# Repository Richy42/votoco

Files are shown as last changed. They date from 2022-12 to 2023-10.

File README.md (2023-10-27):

# Voron Tool Controller
A 3D printer controller board

Inspired by the possibility of Klipper 3D printer firmware (https://www.klipper3d.org/) that allows to have several I/O controller boards, Voron Tool Controller is a small board intended to be mounted on the moving print head assembly of a Voron 3D printer.

This reduces the cabling effort significantly as only power supply and CAN is needed.

PrintHeadController has the following features:
* Based on STM32 , so it is supported by the Klipper firmware out of the box
* TMC2209 on board for the extruder
* Supports the UART configuration of TMC driver
* 12 V and 24 V capable
* 2 Digital inputs
* 3 MOSFET outputs (e.g. hotend heater, fans)
* 1 Thermistor inputs
* BLTouch support
* Debug pins accessible
* Accelerometer ADXL245
* Don't Touch It connector (https://github.com/Richy42/DontTouchIt)









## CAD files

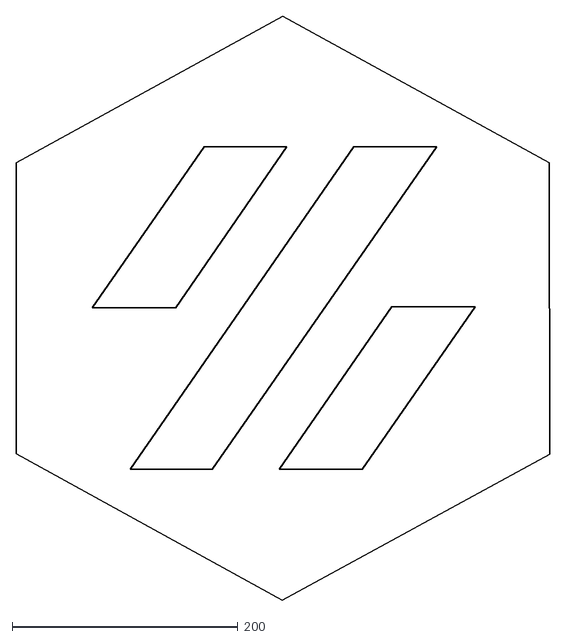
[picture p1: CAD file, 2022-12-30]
kicad/Voron_Design_Plain_Logo.dxf
472.7 x 517.8

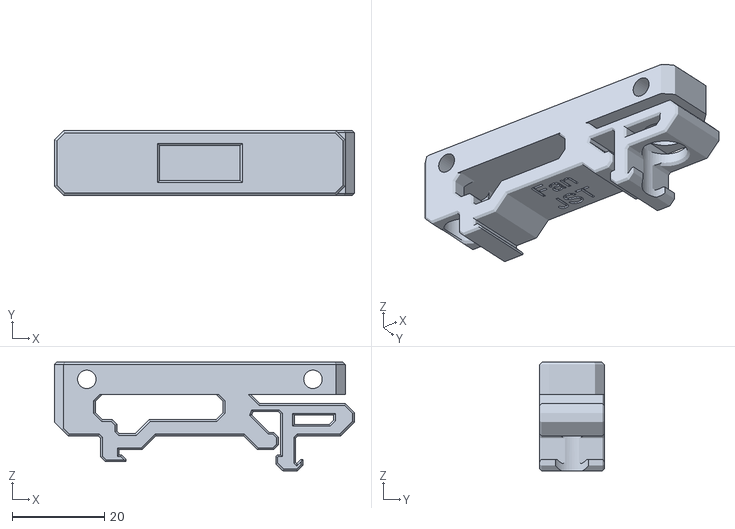
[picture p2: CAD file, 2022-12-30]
kicad/votoco/fan_jst_bracket.stl
65.0 x 14.0 x 23.6

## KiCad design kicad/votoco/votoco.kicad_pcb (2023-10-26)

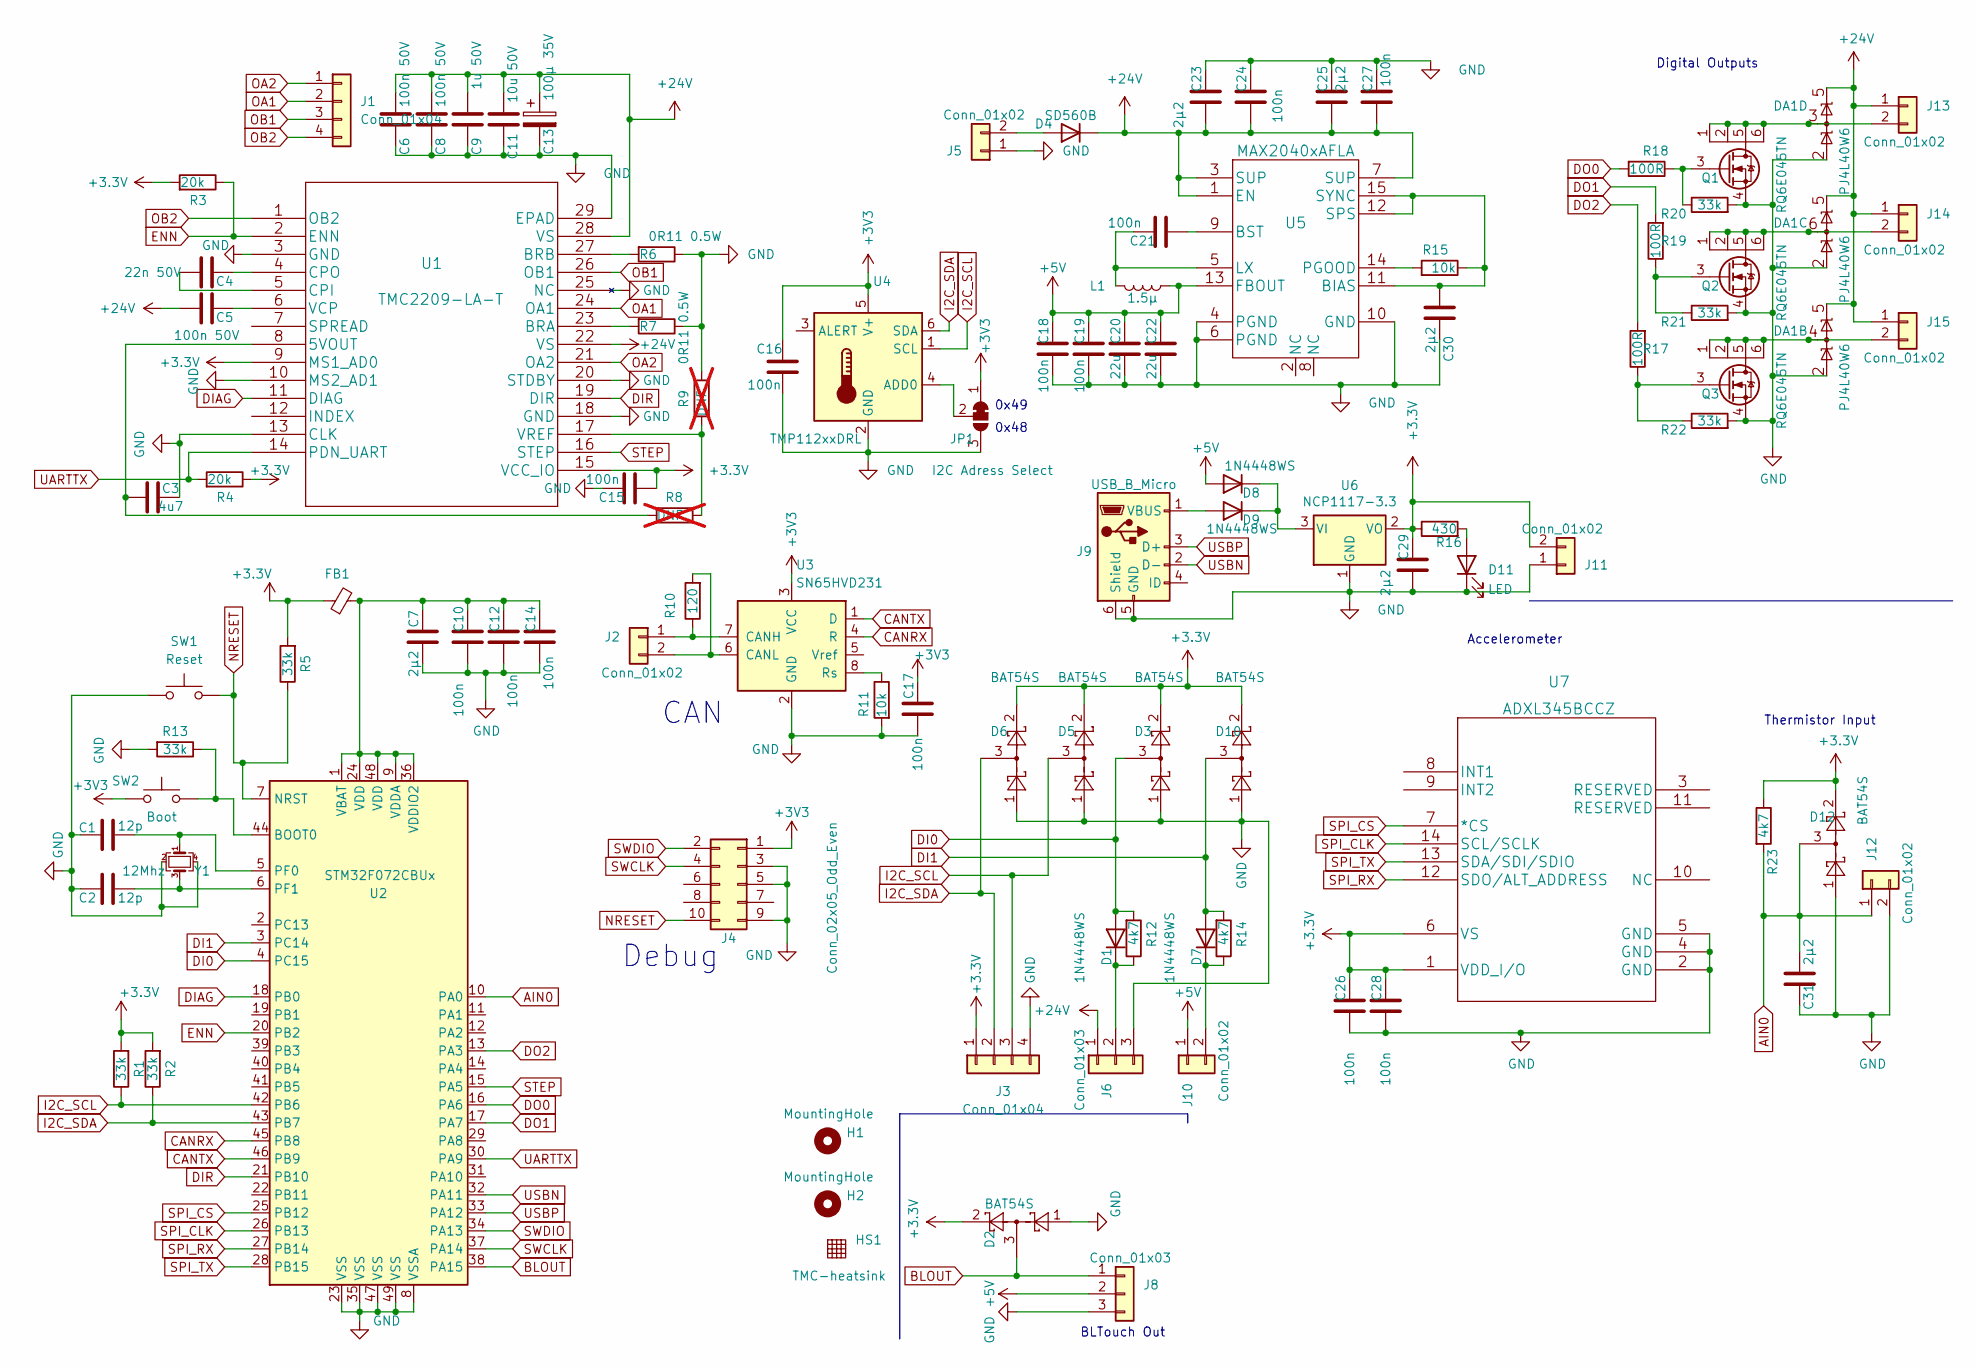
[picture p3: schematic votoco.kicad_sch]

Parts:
C1, C2: 12p; C_0603_1608Metric
C3: 4u7; C_0603_1608Metric
C4: 22n 50V; C_0603_1608Metric
C5, C6, C8: 100n 50V; C_0603_1608Metric
C7, C23, C25, C29, C30, C31: 2µ2; C_0603_1608Metric
C9: 1u 50V; C_0603_1608Metric
C10, C12, C14, C15, C16, C17, C18, C19, C21, C24, C26, C27, C28: 100n; C_0603_1608Metric
C11: 10u 50V; C_0603_1608Metric
C13: 100µ 35V; CP_Elec_6.3x7.7
C20, C22: 22u; C_0603_1608Metric
D1, D7, D8, D9: 1N4448WS; D_SOD-323
D2, D3, D5, D6, D10, D12: BAT54S; SOT-23
D4: SD560B; D_SMB
D11: LED; LED_0603_1608Metric
DA1: PJ4L40W6; SOT-23-6
FB1: FerriteBead_Small; L_0603_1608Metric
H1, H2: MountingHole; MountingHole_3.2mm_M3
HS1: TMC-heatsink
J1, J3: Conn_01x04; JST_PH_B4B-PH-SM4-TB_1x04-1MP_P2.00mm_Vertical
J2, J10, J11, J12, J13, J14, J15: Conn_01x02; JST_PH_B2B-PH-SM4-TB_1x02-1MP_P2.00mm_Vertical
J4: Conn_02x05_Odd_Even; PinHeader_2x05_P1.27mm_Vertical_SMD
J5: Conn_01x02; JST_VH_B2P-VH-B_1x02_P3.96mm_Vertical
J6, J8: Conn_01x03; JST_PH_B3B-PH-SM4-TB_1x03-1MP_P2.00mm_Vertical
J9: USB_B_Micro; USB_Micro-B_Wuerth_614105150721_Vertical_CircularHoles
JP1: I2C Adress Select; SolderJumper-3_P1.3mm_Bridged12_RoundedPad1.0x1.5mm
L1: 1.5µ; L_0805_2012Metric
Q1, Q2, Q3: RQ6E045TN; SOT-457T
R1, R2, R5, R13, R20, R21, R22: 33k; R_0603_1608Metric
R3, R4: 20k; R_0603_1608Metric
R6, R7: 0R11 0.5W; R_0805_2012Metric
R8, R9: DNF; R_0603_1608Metric; not fitted
R10: 120; R_0603_1608Metric
R11, R15: 10k; R_0603_1608Metric
R12, R14, R23: 4k7; R_0603_1608Metric
R16: 430; R_0603_1608Metric
R17, R18, R19: 100R; R_0603_1608Metric
SW1: Reset; SW_Push_1P1T-Pana_EVPAA
SW2: Boot; SW_Push_1P1T-Pana_EVPAA
U1: TMC2209-LA-T
U2: STM32F072CBUx; UFQFPN-48_EP_7x7_Pitch0.5mm
U3: SN65HVD231; SOIC-8_3.9x4.9mm_P1.27mm
U4: TMP112xxDRL; SOT-563
U5: MAX2040xAFLA; MAX2040xAFL
U6: NCP1117-3.3; SOT-223-3_TabPin2
U7: ADXL345BCCZ
Y1: 12Mhz; Crystal_SMD_2520-4Pin_2.5x2.0mm

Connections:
+5V: C18.1, C19.1, C20.2, C22.2, D8.2 (A), J8.2, J10.1, L1.1, U5.13 (FBOUT)
+24V: C5.2, C6.1, C8.1, C9.1, C11.1, C13.1, C23.2, C24.2, C25.2, C27.2, D4.1 (K), DA1.5, J6.1, J13.1, J14.1, J15.1, U1.22 (VS), U1.28 (VS), U5.1 (EN), U5.3 (SUP), U5.7 (SUP)
AIN0: C31.1, D12.3, J12.1, R23.2, U2.10 (PA0)
BLOUT: D2.3, J8.1, U2.38 (PA15)
CANRX: U2.45 (PB8), U3.4 (R)
CANTX: U2.46 (PB9), U3.1 (D)
DI0: D1.2 (A), D3.3, R12.2, U2.4 (PC15)
DI1: D7.2 (A), D10.3, R14.2, U2.3 (PC14)
DIAG: U1.11 (DIAG), U2.18 (PB0)
DIR: U1.19 (DIR), U2.21 (PB10)
DO0: R18.2, U2.16 (PA6)
DO1: R19.2, U2.17 (PA7)
DO2: R17.2, U2.13 (PA3)
ENN: R3.1, U1.2 (ENN), U2.20 (PB2)
GND: C1.1, C2.1, C3.1, C6.2, C7.2, C8.2, C9.2, C10.2, C11.2, C12.2, C13.2, C14.2, C15.1, C16.2, C17.2, C18.2, C19.2, C20.1, C22.1, C23.1, C24.1, C25.1, C26.2, C27.1, C28.2, C29.2, C30.2, C31.2, D2.1, D3.1, D5.1, D6.1, D10.1, D11.1 (K), D12.1, DA1.2, J3.4, J4.3, J4.5, J4.9, J5.1, J6.3, J8.3, J9.5 (GND), J9.6 (Shield), J11.1, J12.2, JP1.3 (B), Q1.4 (S), Q2.4 (S), Q3.4 (S), R6.1, R7.1, R9.2, R11.2, R13.2, R20.2, R21.2, R22.2, SW1.1, U1.3 (GND), U1.10 (MS2_AD1), U1.13 (CLK), U1.18 (GND), U1.20 (STDBY), U1.25 (NC), U1.29 (EPAD), U2.8 (VSSA), U2.23 (VSS), U2.35 (VSS), U2.47 (VSS), U2.49 (VSS), U3.2 (GND), U4.2 (GND), U5.4 (PGND), U5.6 (PGND), U5.10 (GND), U6.1 (GND), U7.2 (GND), U7.4 (GND), U7.5 (GND), Y1.2, Y1.4
I2C_SCL: D5.3, J3.3, R1.1, U2.42 (PB6), U4.1 (SCL)
I2C_SDA: D6.3, J3.2, R2.1, U2.43 (PB7), U4.6 (SDA)
NRESET: J4.10, R5.1, SW1.2, U2.7 (NRST)
unnamed: D1.1 (K), J6.2, R12.1
unnamed: D4.2 (A), J5.2
unnamed: D7.1 (K), J10.2, R14.1
unnamed: D8.1 (K), D9.1 (K), U6.3 (VI)
unnamed: D9.2 (A), J9.1 (VBUS)
unnamed: D11.2 (A), R16.2
unnamed: J2.1, R10.1, U3.7 (CANH)
unnamed: J2.2, R10.2, U3.6 (CANL)
unnamed: DA1.3, J13.2, Q1.1 (D), Q1.2 (D), Q1.5 (D), Q1.6 (D)
unnamed: DA1.6, J14.2, Q2.1 (D), Q2.2 (D), Q2.5 (D), Q2.6 (D)
unnamed: DA1.4, J15.2, Q3.1 (D), Q3.2 (D), Q3.5 (D), Q3.6 (D)
unnamed: JP1.2 (C), U4.4 (ADD0)
unnamed: Q1.3 (G), R18.1, R20.1
unnamed: Q2.3 (G), R19.1, R21.1
unnamed: Q3.3 (G), R17.1, R22.1
unnamed: C3.2, R8.1, U1.8 (5VOUT)
unnamed: R7.2, U1.23 (BRA)
unnamed: R6.2, U1.27 (BRB)
unnamed: C4.2, U1.5 (CPI)
unnamed: C4.1, U1.4 (CPO)
unnamed: C5.1, U1.6 (VCP)
unnamed: R8.2, R9.1, U1.17 (VREF)
unnamed: R13.1, SW2.2, U2.44 (BOOT0)
unnamed: C1.2, U2.5 (PF0), Y1.1
unnamed: C2.2, U2.6 (PF1), Y1.3
unnamed: C7.1, C10.1, C12.1, C14.1, FB1.2, U2.1 (VBAT), U2.9 (VDDA), U2.24 (VDD), U2.36 (VDDIO2), U2.48 (VDD)
unnamed: R11.1, U3.8 (Rs)
unnamed: C30.1, R15.1, U5.11 (BIAS), U5.12 (SPS), U5.15 (SYNC)
unnamed: C21.2, U5.9 (BST)
unnamed: C21.1, L1.2, U5.5 (LX)
unnamed: R15.2, U5.14 (PGOOD)
OA1: J1.2, U1.24 (OA1)
OA2: J1.1, U1.21 (OA2)
OB1: J1.3, U1.26 (OB1)
OB2: J1.4, U1.1 (OB2)
SPI_CLK: U2.26 (PB13), U7.14 (SCL/SCLK)
SPI_CS: U2.25 (PB12), U7.7 (*CS)
SPI_RX: U2.27 (PB14), U7.12 (SDO/ALT_ADDRESS)
SPI_TX: U2.28 (PB15), U7.13 (SDA/SDI/SDIO)
STEP: U1.16 (STEP), U2.15 (PA5)
SWCLK: J4.4, U2.37 (PA14)
SWDIO: J4.2, U2.34 (PA13)
UARTTX: R4.2, U1.14 (PDN_UART), U2.30 (PA9)
USBN: J9.2 (D-), U2.32 (PA11)
USBP: J9.3 (D+), U2.33 (PA12)

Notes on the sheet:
BLTouch Out
Thermistor Input
Debug
CAN
Accelerometer
Digital Outputs
0x48
0x49

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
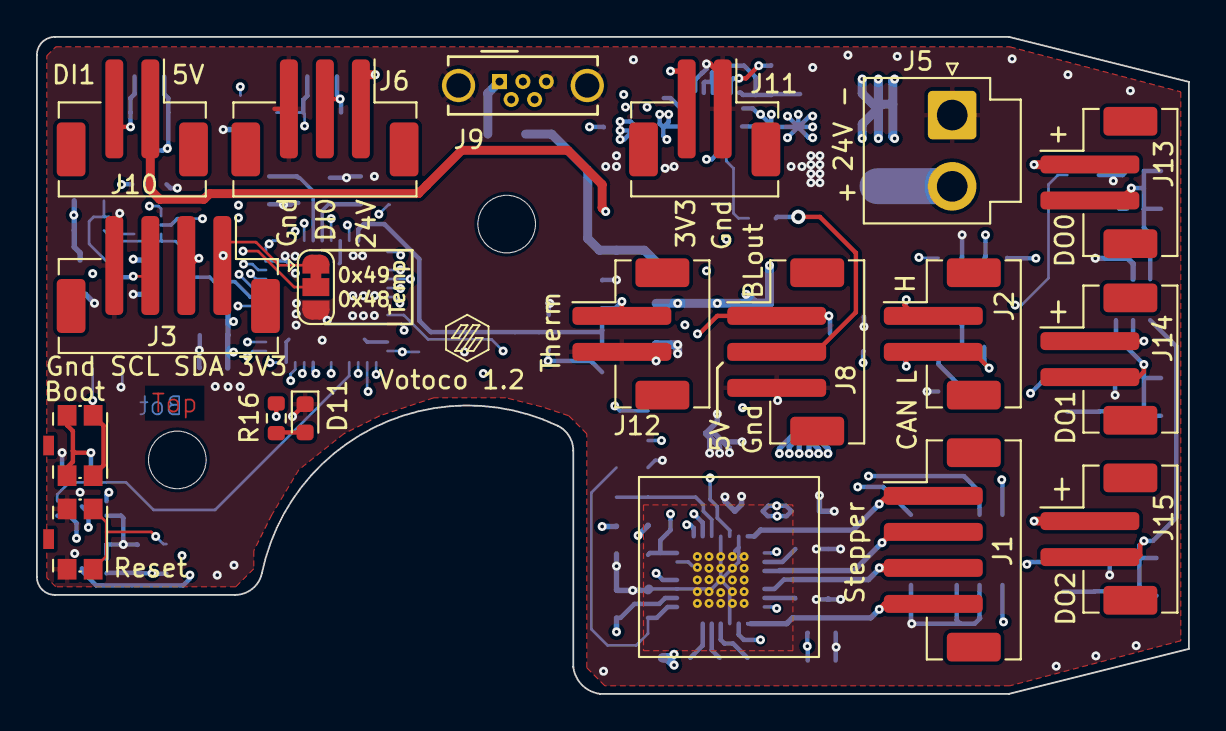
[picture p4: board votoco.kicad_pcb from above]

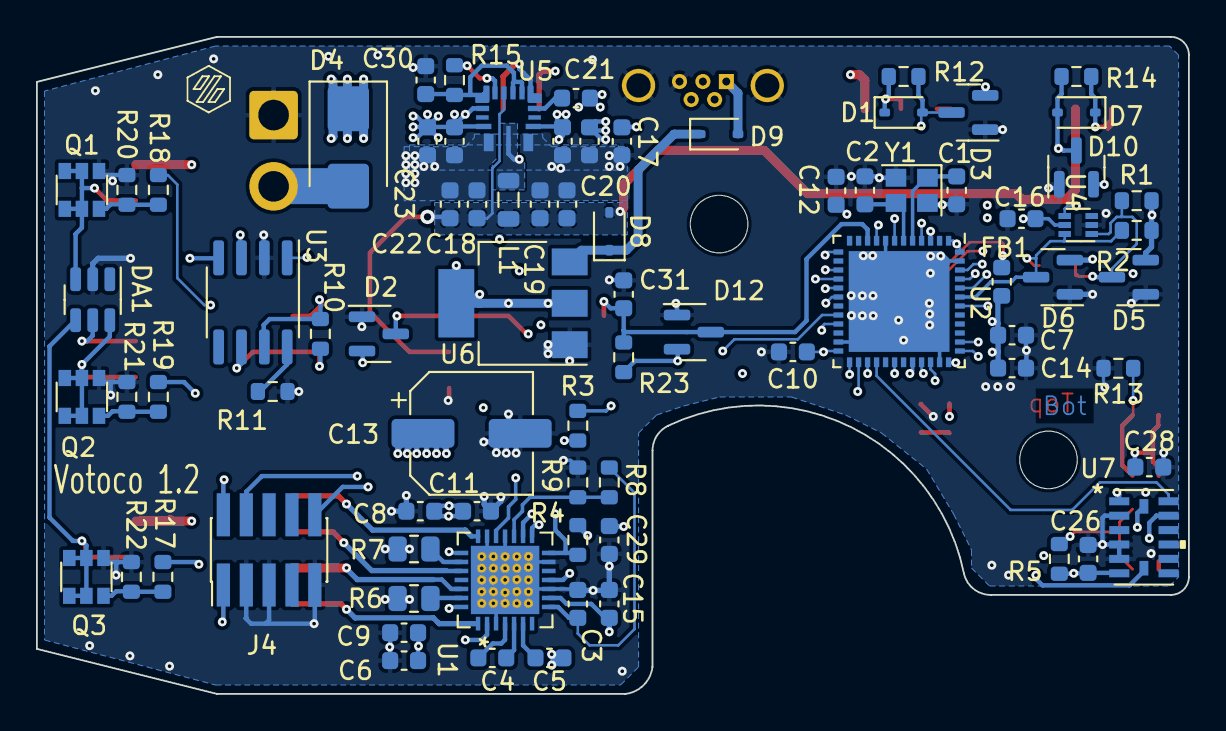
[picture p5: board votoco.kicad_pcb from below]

Board: 4 copper layers, 64.0 x 36.5 mm, 100 parts (79 on the bottom side), 64 nets.

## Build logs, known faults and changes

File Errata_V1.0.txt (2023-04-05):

* R4 should be pullup
* Pullup on ENN missing
* C16 should be 100µ (or several smaler one) - extremely important!

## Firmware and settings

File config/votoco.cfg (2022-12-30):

## Voron Tool Controller configuration for Klipper

# This is not a full Klipper configuration.
# Copy the needed parts over to you Klipper printer.cfg

##############################################################################
## Availablle generic pins

## Thermistor Pins
#gpio26
#gpio27
#gpio28
#gpio29

## Digital Outputs
#gpio08
#gpio09
#gpio10
#gpio11

## Digital Inputs
#gpio00
#gpio01
#gpio02
#gpio03

##############################################################################


## votoco MCU definition
[MCU toco1]
# Change the serial device according yor setup
serial: /dev/serial/by-id/usb-Klipper_rp2040_xxxxx

[extruder]
step_pin: toco1:gpio17
dir_pin: !toco1:gpio16
enable_pin: !toco1:gpio23
heater_pin: toco1:gpio08 # or any other of the digital outputs
sensor_pin: toco1:gpio26 # or any other of the thermistor inputs

[adxl345]
spi_bus:spi1a
cs_pin: toco1:gpio13
#spi_bus:
#spi_software_sclk_pin: toco1:gpio14
#spi_software_mosi_pin: toco1:gpio15
#spi_software_miso_pin: toco1:gpio12
#   See the "common SPI settings" section for a description of the
#   above parameters.


[bltouch]
sensor_pin: ^toco1:gpio24
control_pin: toco1:gpio25

# 

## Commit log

2023-04-05 some error from V1.0 corrected
    [votoco.kicad_pcb, votoco.kicad_sch]
2023-05-26 switched to new mcu
    [votoco.kicad_sch]
2023-06-08 temp sensor added / I2C connector added / layout almost finished
    [votoco.kicad_pcb, votoco.kicad_sch]
2023-06-09 warning clean-up
    [votoco.kicad_pcb]
2023-06-09 warning clean-up finished
    [votoco.kicad_pcb]
2023-06-17 boot0 pull-down-added / uart-tx corrected
    [votoco.kicad_pcb, votoco.kicad_sch]
2023-06-17 V1.1 fabrication files generated
    [votoco-B_Cu.gbr, votoco-B_Mask.gbr, votoco-B_Paste.gbr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]
2023-10-26 footprint corrected / DIR - SPI clk pins exchanged
    [votoco-B_Cu.gbr, votoco-B_Mask.gbr, votoco-B_Paste.gbr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]

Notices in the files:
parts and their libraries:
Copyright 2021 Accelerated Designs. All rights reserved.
